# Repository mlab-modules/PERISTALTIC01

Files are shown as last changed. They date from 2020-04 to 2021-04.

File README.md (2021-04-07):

# Peristaltic Pump - PERISTALTIC01A

A design of universal [peristaltic pump](https://en.wikipedia.org/wiki/Peristaltic_pump). The main design objectives are: 

  * 3D printable contstruction 
  * Use of standard mechanical components
  * Capability to be scalable depending on the application
  
The primary application which initialize the design was use for hydroponics nutritient dosage. [Original design from Phisik](https://github.com/Phisik/Peristaltic-Pump)

## Additional Hardware

Additionally to pump head you will need to get some electronics:

  * Nema stepper motor, e.g 17HS4401S
  * [Stepper motor driver](https://www.mlab.cz/module/HBSTEP01B)
  * 9 pcs of 605Z bearings
  * Power supply 12V 1-2A

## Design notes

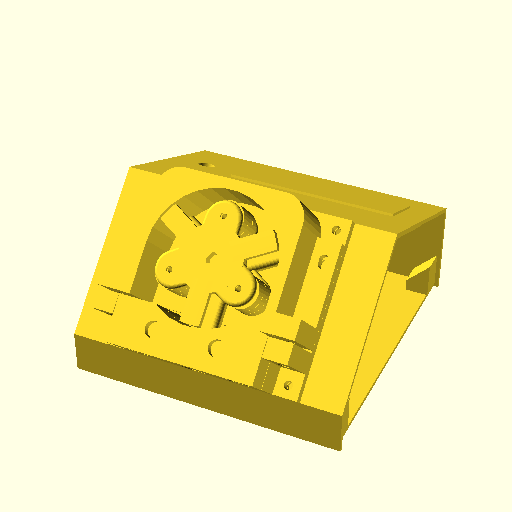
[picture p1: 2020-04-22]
doc/src/img/case-v3.png

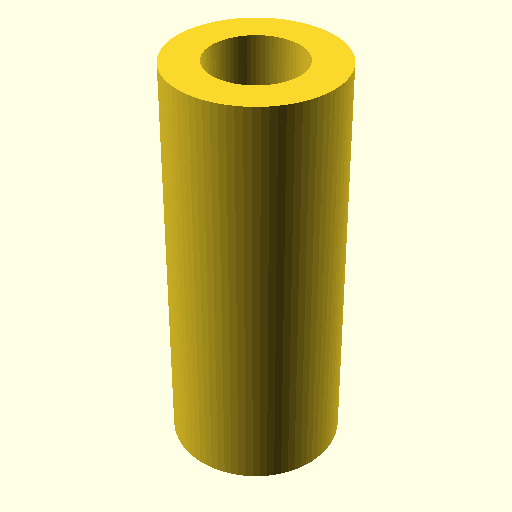
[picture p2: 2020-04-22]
doc/src/img/hose_fixator.png

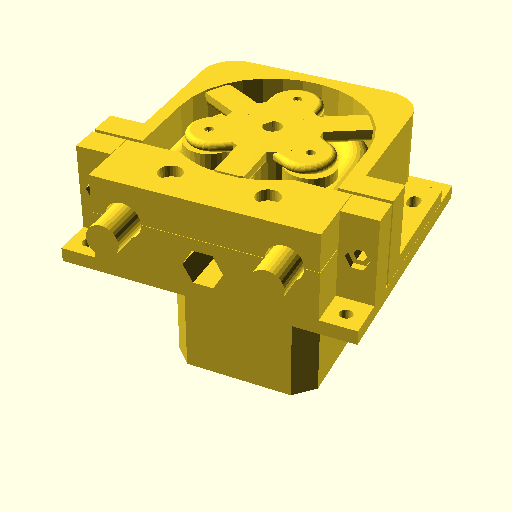
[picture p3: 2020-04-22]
doc/src/img/pump-v3.png

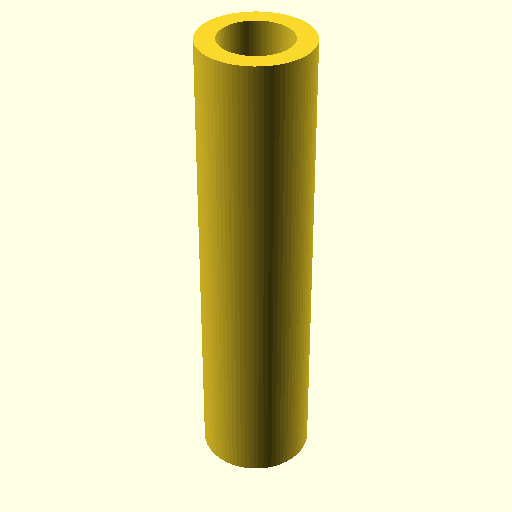
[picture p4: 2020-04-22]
doc/src/img/hose_joiner.png

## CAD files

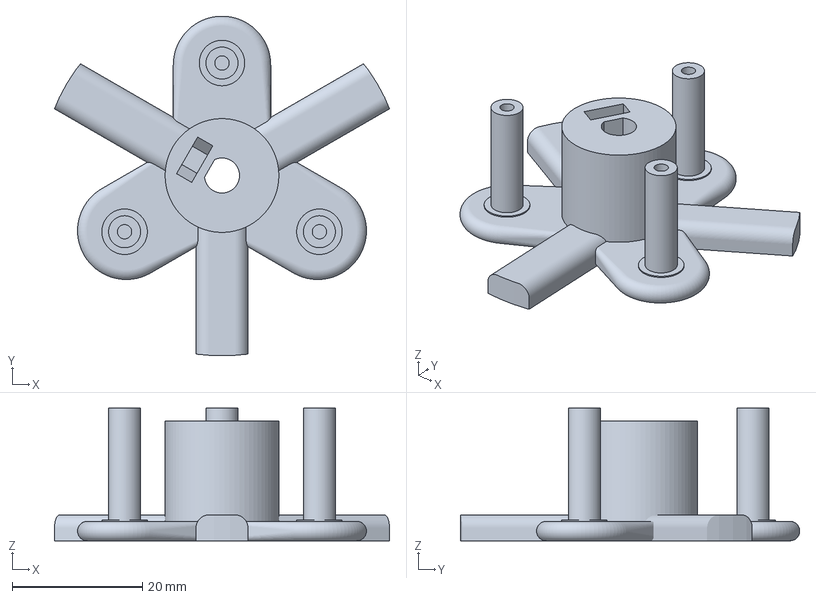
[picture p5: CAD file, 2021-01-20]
hw/amf/rotor_base.amf
51.5 x 52.2 x 20.4 mm

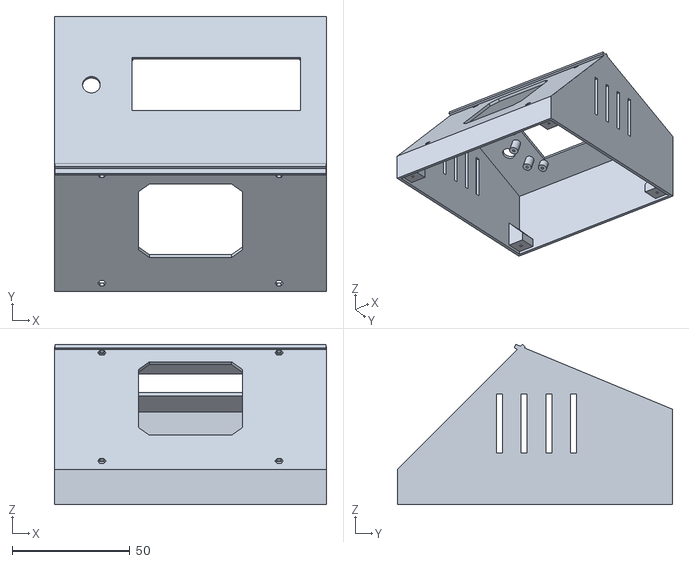
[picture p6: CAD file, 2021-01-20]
hw/stl/4printing/case_top.stl
115.3 x 116.7 x 68.0

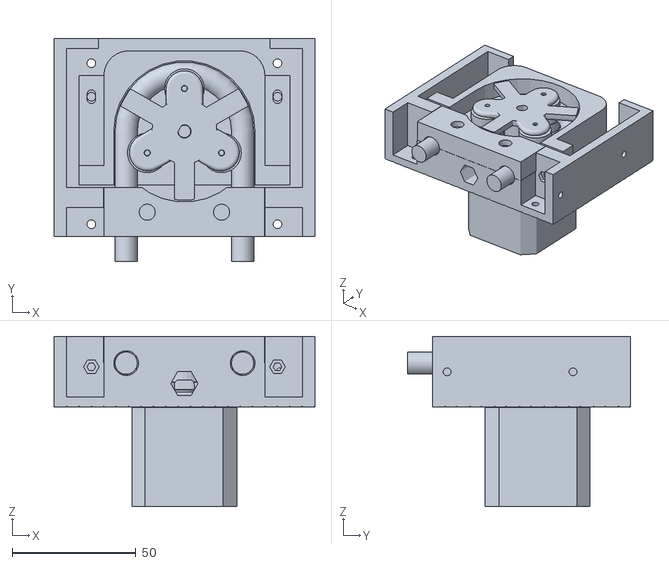
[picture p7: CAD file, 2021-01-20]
hw/stl/assembly/pump.stl
105.3 x 90.0 x 68.7

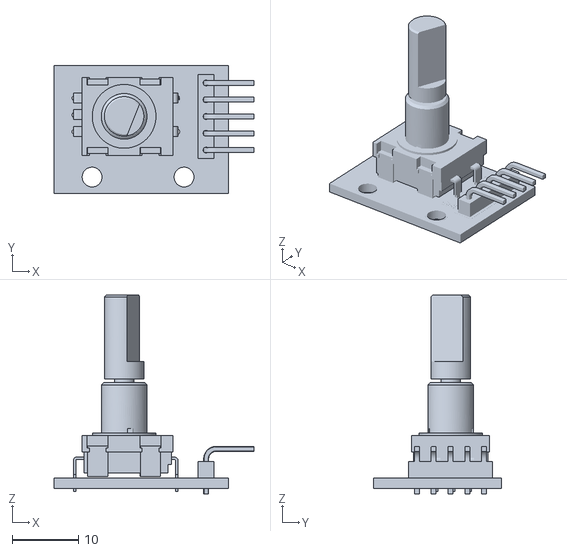
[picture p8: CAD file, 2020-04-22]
hw/stl/ky-040.stl
30.3 x 19.3 x 30.1

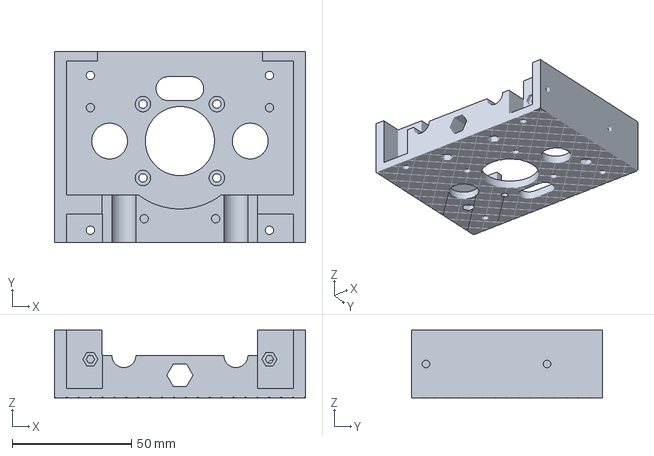
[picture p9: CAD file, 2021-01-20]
hw/amf/stator_base.amf
105.3 x 80.0 x 28.4 mm

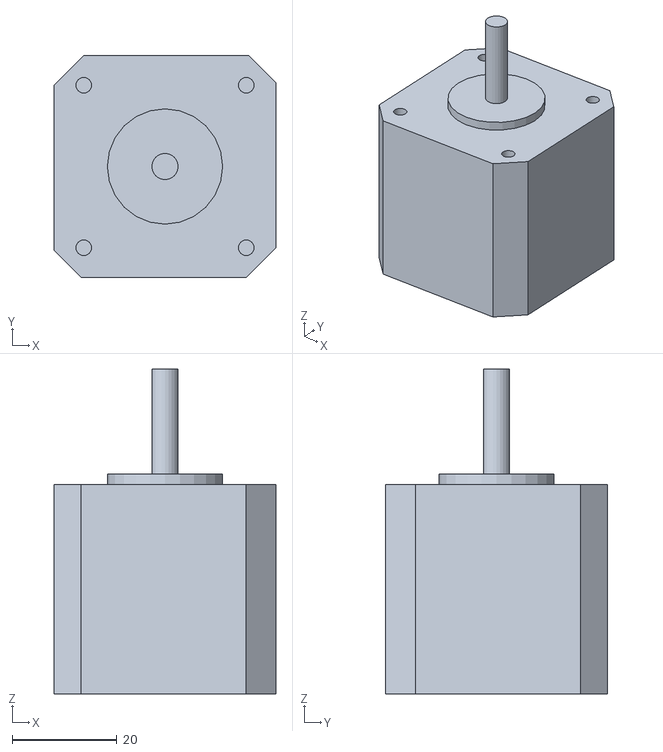
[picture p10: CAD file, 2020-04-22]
hw/stl/Nema17_40h.stl
42.3 x 42.3 x 62.0

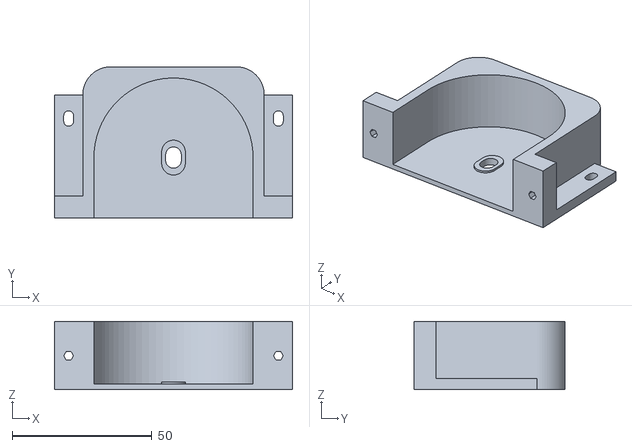
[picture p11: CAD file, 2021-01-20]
hw/stl/4printing/stator_support.stl
85.2 x 54.2 x 24.4

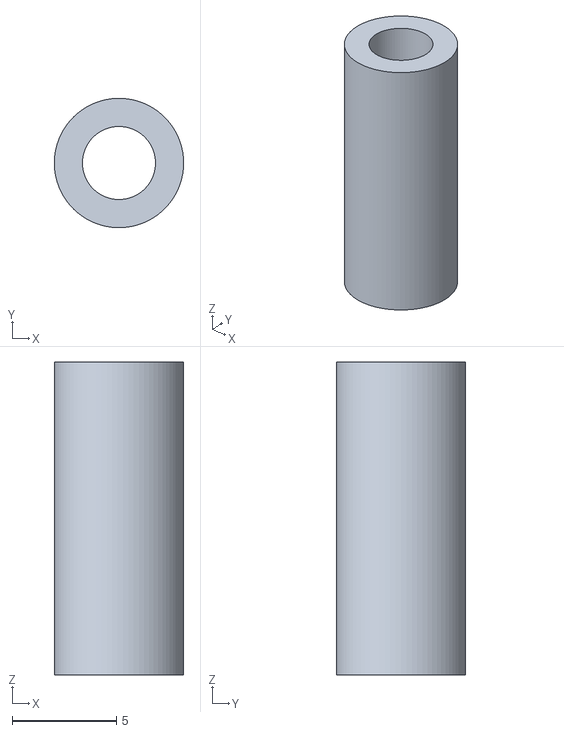
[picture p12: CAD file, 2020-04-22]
hw/stl/hose_fixator.stl
6.20 x 6.20 x 15.0

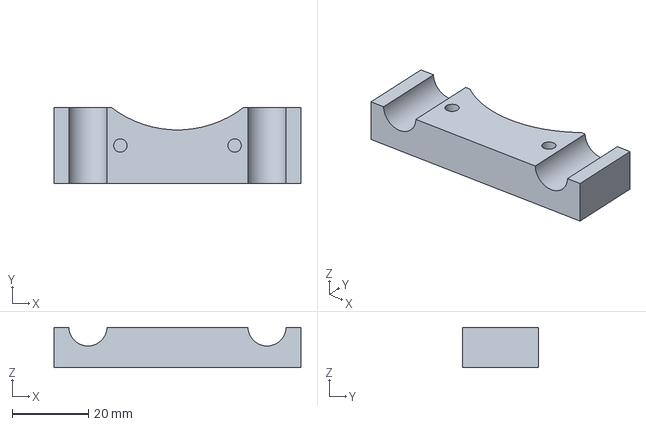
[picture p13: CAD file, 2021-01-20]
hw/amf/stator_cover.amf
64.8 x 19.8 x 10.6 mm

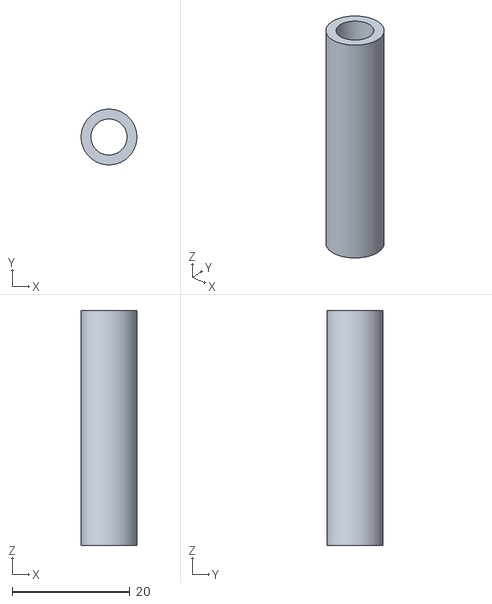
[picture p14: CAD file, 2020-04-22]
hw/stl/hose_joiner.stl
9.50 x 9.50 x 40.0

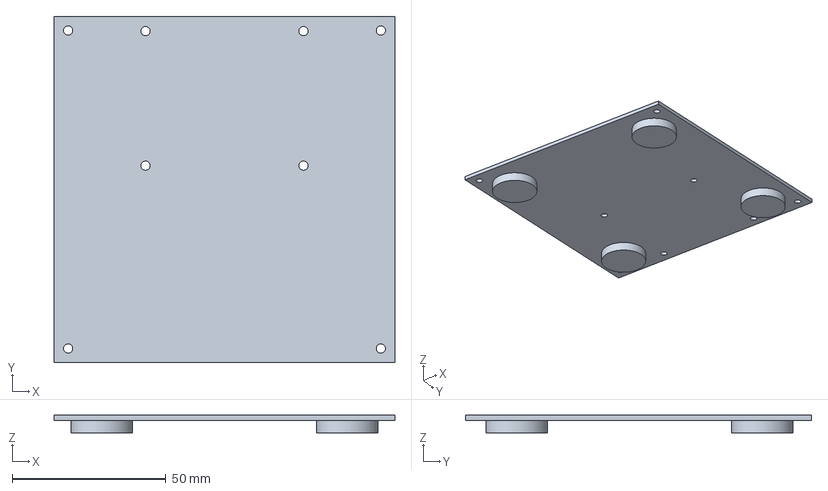
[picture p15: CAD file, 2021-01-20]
hw/amf/case_bottom.amf
111.0 x 112.7 x 5.70 mm

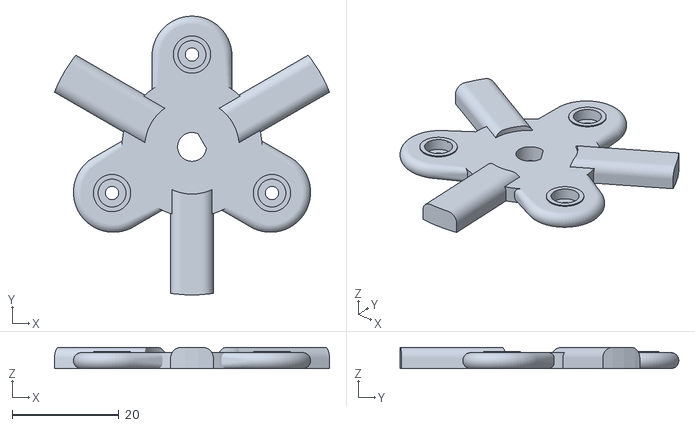
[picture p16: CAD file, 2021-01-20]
hw/stl/4printing/rotor_cover.stl
51.5 x 52.2 x 4.00

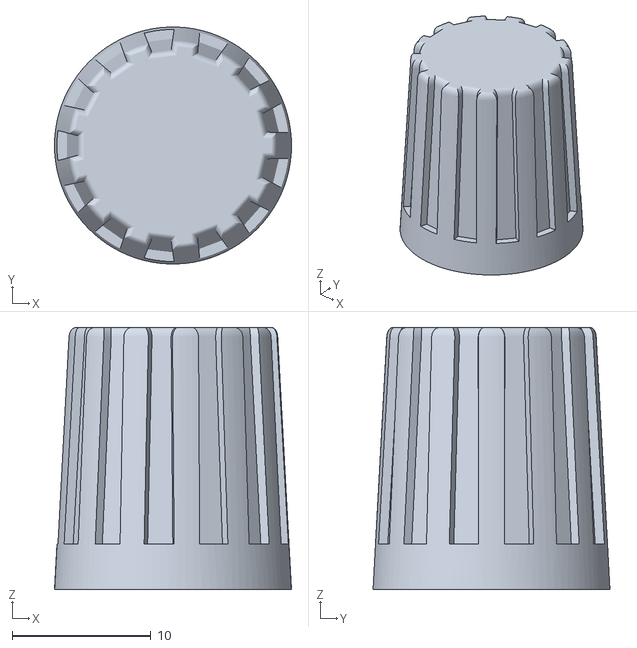
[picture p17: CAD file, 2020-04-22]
hw/stl/encoder-knob.stl
17.1 x 17.1 x 18.9

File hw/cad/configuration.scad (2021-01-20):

// Created by Phisik on 2018-12-16
// Main settings header for peristaltic pump

// Licence GPL

// some extra gap for clean difference render in preview
eps = 0.1;

// Part smoothness, the more the better
$fn = 100;

layer_height = 0.25;

// Silicon hose settings
//====================================================================================

// NB! The larger the hose radius the higher torque is required
r_hose = 24;        // radius of hose center line
                    // Update: after addition of groove hose center is at r_hose + hose_groove
d_hose = 9;         // hose diameter

hose_wall = 1.5;   // hose wall thickness
					// NB! hose_wall affects both stator & rotor geometry
					
hose_clearance = 0.2;   // extra clearance between hose & bearings
						// NB! hose_clearance affects only rotor geometry
						// If you experience lack of suction reduce hose_clearance 
						// If motor misses steps increase hose_clearance, take motor with higher 
						// torque or hose with thinner wall

hose_fitting_delta_d = 1; // difference between hose and hose fitting diameter
						
						
// Stator settings
//====================================================================================
wall = 4;             // wall thickness, should be larger than hose_groove by 1mm or more
hose_groove = 0;     // NB! Rudiment form v1. Do not change. 
					 // groove depth for hose to stay in place 

h_base = 4;             // height of stator base
h_support_base = 2;		// height of support base

stator_support_gap = 1;		// gap between support & stator base for spring tension

stator_facet = 10;   // facets of outer support corners

mount_width  = 8;
mount_length = 10.12;

d_screw = 3.5;           // screw diameter
d_nut = 6.5;             // nut & screw head diameter
d_nut_tight = 5.5/0.87; // nut diameter for nuts to be fitted with soldering iron

l_handle = 10;

r_water_sink = 5.5;

need_nut_cuts_in_support = 0; // cut holes for nuts in support
need_nut_cuts_in_stator  = 1; // cut holes for support nut in stator

hose_fixator_length = 15;  // length of hose inset for fixing it on the stator


// Bearing settings
//====================================================================================
bearingNum = 3;     // Number of bearings per arm

h_bearing = 5;      // bearing height
d_bearing = 16;     // OD
d_bearing_axis = 5;         // ID
w_axis = 1;         // thickness of inner bushing



// Rotor settings
//==================================================================================== 
d_rotor = 17.5;   // Outer rotor diameter

arm_num = 3;    // number of rotor arms
w_arm  = 15;    // arm width
h_arm = 3;      // arm height

enable_hose_guides = 1;
w_hose_guide = 8;
hose_guide_clearance = 0.75;
r_hose_guide_facet = 2;

gap = 0.2;      // some clearance between joins & moving parts

arm_clearance = 4;  // clearance between arm and stator

bearing_axes_clearance = 0.075;  	     // clearance on rotor base between bearings and axes
rotor_bearing_axes_clearance = 0.3;  // clearance on rotor cap between axes and holes
bearing_clearance = 1; 				 // distance from stator base to the lowest arms

// 1602 lcd settings
//====================================================================================
y_lcd_hole = 31;
x_lcd_hole = 75;
d_lcd_hole = 3;

l_lcd_plate = 80;
w_lcd_plate = 36.11;
h_lcd_plate = 1.6;

l_lcd = 71.5;
w_lcd = 24.5;
h_lcd = 8.75;

x_lcd_shift = -0.1;
y_lcd_shift = +0.75;

l_lcd_i2c = 42;
w_lcd_i2c = 19;
h_lcd_i2c = 1.5;


// Nema 17 settings
//====================================================================================
nema_screw_distance = 31;  
nema_shaft_diameter = 5.5;
nema_shaft_height = 25;
nema_knob_diameter = 23;
nema_knob_height = 2.5;
nema_width = 42.3;
nema_angle_cut = 4;

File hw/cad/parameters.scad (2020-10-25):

maximum_printable_size = 150;

global_clearance = 0.5;

// screw length step - minimum difference in length between two types of screws
basic_screw_length = 5;

//Screw diameter and nut for M10 [mm]
M10_screw_diameter = 10.4;
M10_head_height = 10;
M10_head_diameter = 16+0.5;
M10_nut_height = 10.5;
M10_nut_diameter = 25.5;
M10_nut_pocket = 22.3;

//Screw diameter for M8 [mm]
M8_screw_diameter = 8.6;
M8_head_height = 8;
M8_head_diameter = 13.5;
M8_nut_height = 7.5;
M8_square_nut_thin_height = 4.5;
M8_nut_diameter = 14.4 + 0.5;
M8_nut_pocket = 13 + 0.5;
M8_washer_diameter = 16;
M8_washer_thickness = 1.5;


//Screw diameter and nut for M6 [mm]
M6_screw_diameter=6.5;
M6_head_diameter = 10+0.5;
M6_head_height = 6;
M6_nut_height = 4.9;
M6_nut_diameter = 11.8;
M6_nut_pocket = 10.4;
M6_square_nut_height = 3;
M6_square_nut_diameter = 10;

//Screw diameter and nut for M5 [mm]
M5_screw_diameter=5.5;
M5_head_height = 5;
M5_head_diameter = 13+0.5;
M5_nut_height = 4.5;
M5_nut_diameter = 9.4;
M5_nut_pocket = 8.4;

//Screw diameter and nut for M4 [mm]
M4_screw_diameter=4.5;
M4_screw_head_height = 4;
M4_nut_height = 3.2;
M4_nut_diameter = 8.4;
M4_nut_pocket = 7.5;

//Screw diameter and nut for M3 [mm]
M3_screw_diameter = 3.2;
M3_nut_height = 2.7;
M3_nut_diameter = 6.6;
M3_nut_pocket = 5.6;
M3_screw_head_height = 3;

//Screw diameter and nut for M2,5 [mm]
M2_5_screw_diameter = 2.7;
M2_5_nut_height = 2.3;
M2_5_nut_diameter = 6;
M2_5_nut_pocket = 5.5;

// kulove lozisko

bearing_efsm_08_h = 33+1;
bearing_efsm_08_m = 22;
bearing_efsm_08_db = 18;
bearing_efsm_08_ag = 10.5;
bearing_efsm_08_n = M4_screw_diameter;
bearing_efsm_08_a1 = 5.5;
bearing_efsm_08_d = 8.25;
bearing_efsm_08_B = 8; // ball height

bearing_efsm_10_h = 38+1;
bearing_efsm_10_m = 26;
bearing_efsm_10_db = 21.9;
bearing_efsm_10_ag = 12+0.2;
bearing_efsm_10_n = M5_screw_diameter;
bearing_efsm_10_a1 = 6.5;
bearing_efsm_10_d = 10.25;


bearing_efsm_12_width = 40+1;
bearing_efsm_12_h = bearing_efsm_12_width;
bearing_efsm_12_boltd = 28/2; // polovina vzdalenosti mezi srouby
bearing_efsm_12_m = bearing_efsm_12_boltd*2;
bearing_efsm_12_db = 25;
bearing_efsm_12_ag = 13;
bearing_efsm_12_a1 = 7;
bearing_efsm_12_n = M5_screw_diameter;
bearing_efsm_12_d = 12.15;
bearing_efsm_12_B = 10; // ball height
bearing_efsm_space = 1;

bearing_efsm_17_width = 54+1;
bearing_efsm_17_h = bearing_efsm_17_width;
bearing_efsm_17_boltd = 38/2; // polovina vzdalenosti mezi srouby
bearing_efsm_17_m = bearing_efsm_17_boltd*2;
bearing_efsm_17_db = 35;
bearing_efsm_17_ag = 18;
bearing_efsm_17_n = M6_screw_diameter;
bearing_efsm_17_a1 = 10;
bearing_efsm_17_B = 17; // ball height

//limcove lozisko
bearing_EFOM_10_L=26; //celkova sirka zakladny
bearing_EFOM_10_d1=10.3;//diametr otvoru real=10 mm
bearing_EFOM_10_dB=22;//diametr vystupku pro ulozeni lozika
bearing_EFOM_10_H=52;//celková delka zakladny
bearing_EFOM_10_J=36;// hole pitch
bearing_EFOM_10_A1=6.5;//vyska pouzdra
bearing_EFOM_10_Ag=12;//celkova vyska
bearing_EFOM_10_N1=5;//sirka otvoru pro sroub
bearing_EFOM_10_N2=8;//delka otvoru pro sroub
bearing_EFOM_10_m=36;//roztec der pro sroub
bearing_EFOM_10_h=9;//vyska lozika

608_bearing_outer_diameter = 22.3;
608_bearing_inner_diameter = 16;
608_bearing_thickness = 7.1;


// 20 KG servo parameters

servo_20kg_axis_offset = 9.375; // jak je osa mimo stredu
servo_20kg_body_x = 42;
servo_20kg_body_y = 21;
servo_20kg_body_z = 40;
servo_20kg_thread_x = 49/2;
servo_20kg_thread_y = 10/2;
servo_20kg_body_below = 10; // jak hluboko je tělo serva pod drzaky na srouby
servo_20kg_below = 25.8; // jak hluboko je páka serva pod drzaky na srouby

servo_20kg_bolt_d = 2.5+0.3;
servo_20kg_nut_d = 5+0.3;


//strain gauge
strain_gauge_width = 12.7;
strain_gauge_length = 75.1;
strain_gauge_screw_distance = 10;

//ALU profile
ALU_profile_width = 30.3;
ALU_profile_holder_wall_thickness = 3;
ALU_profile_groove_width = 8;

//pillow block bearing
//https://www.igus.eu/product/372
//Part no. KSTM-08
KSTM08_screws_distance = 33;         //m
KSTM08_screws_holes_diameter = 4.5;  //d2
KSTM08_flange_thickness = 6;         //h3
KSTM08_case_width = 9;               //C1
KSTM08_case_length = 47;             //a
KSTM08_ball_width = 12;              //B

//ložiska pro malý rotor
bearing_outer_diameter = 10.2;    // Rozměr B1 v nákresu s přídavkem na toleranci otvoru
bearing_thickness = 4;        // Rozměr B2 v nákresu
//bearing_shaft_length = 19.5;    // Rozměr B3 v nákresu, Originalni hodnota 19.5
bearing_shaft_length = 20;    // Rozměr B3 v nákresu

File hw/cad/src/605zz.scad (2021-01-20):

module 605zz() {
	difference(){
		cylinder(d=14, h=5);
		cylinder(d=11, h=5);
	}
	difference(){
		cylinder(d=7, h=5);
		cylinder(d=5, h=5);
	}

	translate([0,0,0.25])
	difference(){
		cylinder(d=11, h=4.5);
		cylinder(d=7, h=4.5);
	}
}

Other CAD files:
hw/stl/4printing/stator_base.stl
hw/amf/case_top.amf
hw/stl/4printing/rotor_base.stl
hw/amf/rotor_cover.amf
hw/stl/4printing/stator_cover.stl
hw/cad/src/case-v3.scad
hw/amf/stator_support.amf
hw/cad/src/4printing/case_bottom.scad
hw/cad/src/4printing/case_top.scad
hw/cad/src/4printing/rotor_base.scad
hw/cad/src/4printing/rotor_cover.scad
hw/cad/src/4printing/stator_base.scad
hw/cad/src/4printing/stator_cover.scad
hw/cad/src/4printing/stator_support.scad
hw/cad/src/assembly/case.scad
hw/cad/src/assembly/pump.scad
hw/cad/src/assembly/pump_mount.scad
hw/cad/src/hose_fixator.scad
hw/cad/src/hose_joiner.scad
hw/cad/src/lcd1602.scad
hw/cad/src/pump-v3.scad
hw/stl/4printing/case_bottom.stl
hw/stl/4printing/pump.stl

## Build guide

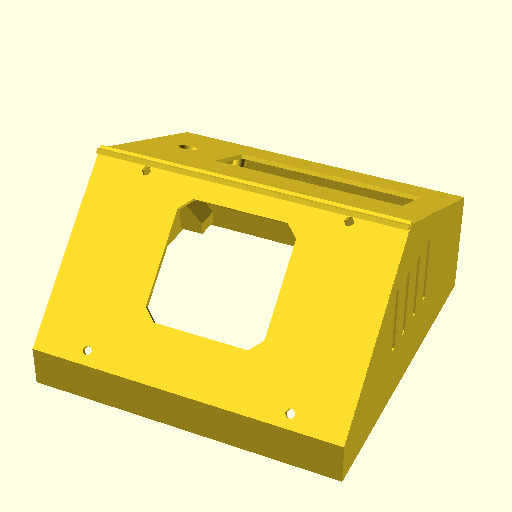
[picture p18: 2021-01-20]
doc/src/img/4printing/case_top.png

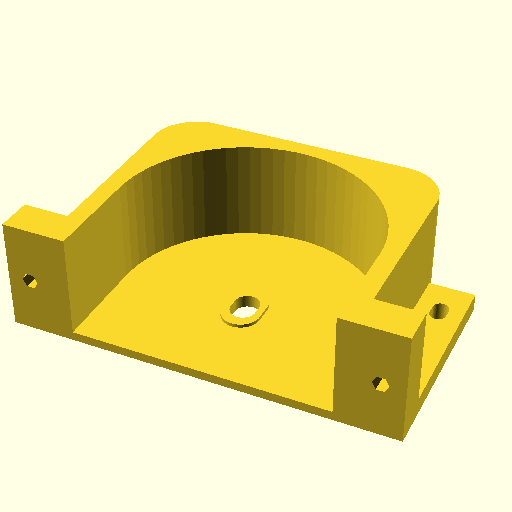
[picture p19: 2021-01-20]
doc/src/img/4printing/stator_support.png

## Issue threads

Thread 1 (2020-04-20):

Výchozí konstrukce peristaltické pumpy

kaklik, 2020-04-20:
Na [Thingiverse](https://www.thingiverse.com/search?q=peristaltic+nema&type=things&sort=relevant) je třeba najít nějaký rozumně kvalitní scad zdroják na peristaltickou pumpu pro motor formátu [NEMA17](https://en.wikipedia.org/wiki/NEMA_stepper_motor).

Nalezený zdroják je potřeba prověřit a nahrát do tohoto repozitáře.

JanKott, 2020-04-21:
Prošel jsem na thingiverse peristaltické pumpy a našel následující:

Nejlepší kandidát bych řekl že je toto
https://www.thingiverse.com/thing:3148717/files
Používá NEMA motor a 6 ložisek 605zz.
Je tam i poměrně dlouhé video kde prezentuje výsledek.

Další varianty jsou tyto:

https://www.thingiverse.com/thing:3591068
Původně navrhováno pro hydroponii, nikdy nedotaženo. Bez použití ložisek.

https://www.thingiverse.com/thing:2378810/files
Používá HS-755MG servo a 6 625 kuličkových ložisek. Dokončený vývoj (funkční).

https://www.thingiverse.com/thing:2856784/files
Tohle je asi jen mount pro NEMA17? Zdá se že tam neni rotační část pro upevnéní ložisek. Musel bych projít ten .scad

https://www.thingiverse.com/thing:1572181
Varianta bez ložisek. Zdá se že tuhle variantu většina motorů neutáhne.

https://www.thingiverse.com/thing:8964
Opět plně plastová varianta, nedokončená.

https://www.thingiverse.com/thing:454702
Planetární převodovka upravená jako peristaltická pumpa.

kaklik, 2020-04-21:
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

Souhlasím

> https://www.thingiverse.com/thing:2856784/files
> Tohle je asi jen mount pro NEMA17? Zdá se že tam neni rotační část pro upevnéní ložisek. Musel bych projít ten .scad

Tohle je myslím trochu horší varianta, neboť neřeší možnost dilatace přesností mezi rotorem a statorem.

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

Tyhle různé alternativy planetových převodovek provozované  jako peristaltické pumpy by byly pěkné. Ale  bylo by nutné nějak zajistit, aby rotor měl vůči statoru nějakou možnost dilatování nepřesností.  Možná by to šlo zařídit snížením tuhosti vnějšího kroužku statoru, ale je to úkol pro samostatný vývoj.

JanKott, 2020-04-22:
Převzal jsem tedy soubory z vybraného projektu na thingiverse. Soubory jsem uložil podle připravené struktury souborů a dogeneroval jsem AMF a GCODE soubory pro tisknutelné části.
Do Makefile jsem doplnil volání make print, které generuje pouze AMF a GCODE pro tisknutelné části.

JanKott, 2021-01-20:
Doplnim do projektu nástroje amfsort a merge_slic3r_conf a přidám github actions na make po každém push.

kaklik, 2021-02-04:
Github actions je funkční.

Closed 2021-02-04.

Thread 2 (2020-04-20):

Úprava uchyceni peristaltické pumpy

kaklik, 2020-04-20:
Nalezenou konstrukci z issue #1  je potřeba upravit tak, aby bylo možné celé čerpadlo uchytit na [základní desku MLAB](https://github.com/MLAB-project/Modules/blob/master/mechanical/ALBASE1521/doc/ALBASE1521.cs.pdf).

Je potřeba uvažovat že pump může vedle sebe být více a je tak potřeba šetřit místem.
Na stejnou desku by se zároveň měla vejít i elektronika, která se bude primárně skládat z modulu [HBSTEP01B](https://www.mlab.cz/module/HBSTEP01B) a nějakého vhodného rozhraní pro jeho ovládání.  Například kombinace modulů [I2CSPI](https://www.mlab.cz/module/I2CSPI01A) a [USBI2C](https://www.mlab.cz/module/USBI2C01A). Tyto dva poslední moduly mohou obsluhovat jeden až čtyři moduly HBSTEP01B.

JanKott, 2020-10-25:
Aktualizoval jsem modul stator_base tak, aby šlo čerpadlo uchytit na základní desku MLAB ALBASE1521.
Doplnil jsem do složky assembly soubor pump_mount.scad kde je naznačena jedna z možností jak uchytit 4 pumpy. Nevím ovšem, jestli se doprostřed vejdou menší moduly mezi NEMA motory jak je naznačeno, protože nevím jaký je jejich přesah.

Closed 2020-10-25.

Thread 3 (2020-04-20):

Úprava konstrukce pumpy pro koupitelnou silikonovou hadičku

kaklik, 2020-04-20:
Peristaltickou pumpu bude potřeba upravit tak, aby umožnila použití [některé koupitelné silikonové hadičky](https://www.tme.eu/cz/katalog/opleteni-a-buzirky_100072/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).

Preferovaný vnitřní průměr je zřejmě 6 nebo 8mm.

kaklik, 2020-04-21:
Další dodavatelé hadiček vhodných do peristaltické pumpy:

- [Gumex](https://www.gumex.cz/produkty/hadicky-ze-silikonu-115?strana=1&pocet=20&vypis=obrazkovy)
- [GMS](https://www.gms.cz/drinktec-silikon)
- [Konekt-hadice](https://www.konekt-hadice.cz/Beztlaka-Silikonova-hadicka-d923.htm)
- [Rubena](https://eshop.rubena.cz/silikonove-hadicky/c-2208/)
- [Kompresory Vzduchotechnika](https://www.kompresory-vzduchotechnika.cz/silikonova-hadicka-12-8-mm/)

kaklik, 2020-10-24:
Default návrhové parametry jsou zřejmě pro hadičku průměru 9mm a tloušťkou stěny 1,5mm.

Takové hadičky mají například tito dodavatelé:

- [gumex](https://www.gumex.cz/Product/VariantDetail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)
- [rubena](https://eshop.rubena.cz/hadicka-9-15-mvq60/d-149629-c-2208/)

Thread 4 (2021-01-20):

Úprava konstrukce pro dostupnější ložiska 625Z

kaklik, 2021-01-20:
Současná konstrukce je navržena pro ložiska 605Z, které má menší vnější průměr. Ložiska 625Z s v nějším průměrem 16 mm se tak do rotoru pumpy nevejde.

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

Řešením je zjistit, zda lze v modelu změnit parametry ložiska tak, aby ostatní díly modelu byly přepočítány způsobem, který zachová funkčnost.

JanKott, 2021-01-20:
Upraveno a přegenerováno.

kaklik, 2021-02-04:
Do upraveného dílu ložiska pasují. :)

Closed 2021-02-04.

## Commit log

2020-04-22 mlab-modules/PERISTALTIC01#1 Initial commit of peristaltic pump taken from https://www.thingiverse.com/thing:3148717
    [605zz.scad, Nema17_40h.stl, case-v3.scad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]
2020-10-25 mlab-modules/PERISTALTIC01#2 Updated pump base to enable mounting on MLAB base ALBASE1521.
    [configuration.scad, parameters.scad, pump-v3.scad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]
2020-10-25 mlab-modules/PERISTALTIC01#2 Updated Makefile and all generated files.
    [case_bottom.amf, case_top.amf, case_top.stl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]
2020-11-13 mlab-modules/PERISTALTIC01#2 Removed bolts from print and added V-shaped cut-outs to the bottom.
    [pump-v3.scad, stator_base.amf, stator_base.stl]
2021-01-20 mlab-modules/PERISTALTIC01#1 Updated slicer configuration to match with authors recommendations.
    [rotor_base.scad, rotor_cover.scad]
2021-01-20 mlab-modules/PERISTALTIC01#4 Resized pump to fit 625Z bearing instead of 605Z.
    [605zz.scad, case_bottom.amf, case_top.amf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]
